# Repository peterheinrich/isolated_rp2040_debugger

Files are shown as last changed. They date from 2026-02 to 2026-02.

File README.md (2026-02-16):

# STATUS: First Prototype in Production
This design is currently untested ...

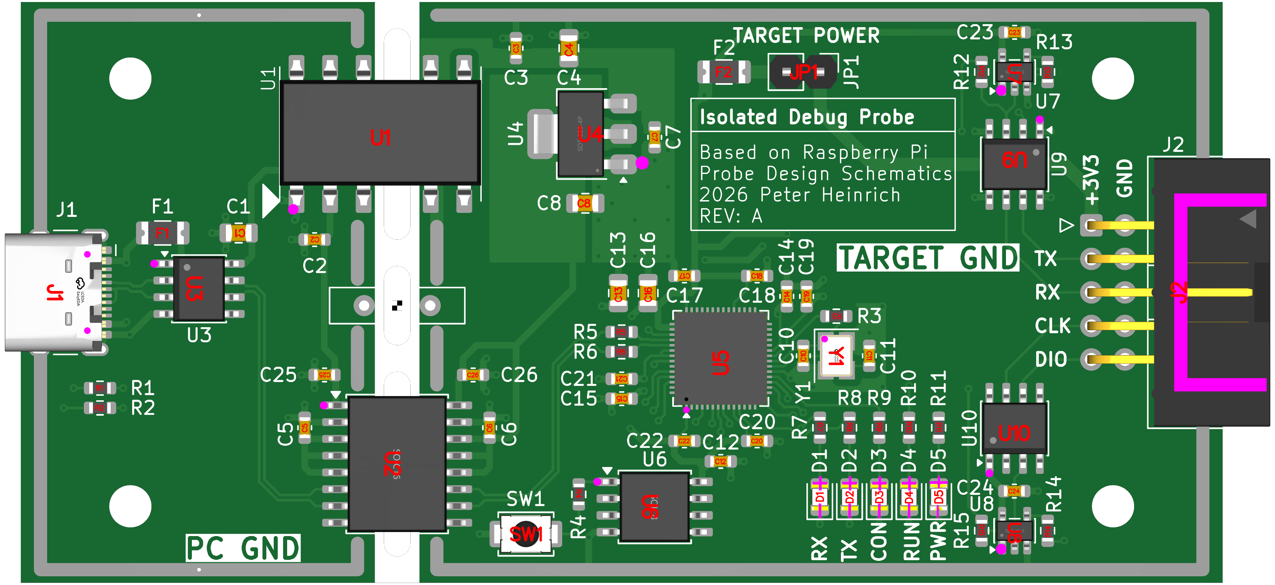
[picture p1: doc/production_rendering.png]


# Isolated RP2040 Debug Probe

An electrically isolated CMSIS-DAP debug probe based on the Raspberry Pi Debug Probe design, with full USB galvanic isolation for improved safety and robustness when debugging embedded hardware.

This project recreates the Raspberry Pi Debug Probe hardware from the published schematic and adds:

- USB full-speed isolation
- ESD protection on both USB and target ports
- Isolated DC/DC power for the target side
- Improved protection against ground loops and high-energy faults

---

## ⚠️ Important Disclaimer

This is an independent, community-made hardware design.

This project is not affiliated with, endorsed by, or supported by Raspberry Pi Ltd.
“Raspberry Pi” is a trademark of Raspberry Pi Ltd.

The original debug probe design and firmware are created by Raspberry Pi.
This repository only provides a compatible hardware implementation based on their publicly released schematic.

Original documentation:
https://www.raspberrypi.com/documentation/microcontrollers/debug-probe.html

---

## Why an Isolated Debug Probe?

Standard USB debug probes share ground between:

- your PC
- the probe
- the target device

This is usually fine — until it isn't.

Real-world embedded targets often include:
- switching power supplies
- motor drivers
- high-current loads
- long cable harnesses
- industrial equipment

Connecting a non-isolated probe can cause:

- ground loops
- USB disconnects
- corrupted SWD communication
- damage to the target
- damage to your laptop USB port

This design introduces galvanic isolation between the USB host and the target interface (SWD/UART), protecting both sides.

---

## Features

- RP2040-based CMSIS-DAP probe
- SWD debugging (OpenOCD, ... compatible)
- USB CDC UART bridge
- Full USB isolation
- Isolated target power domain
- Drop-in compatible with existing Raspberry Pi Debug Probe software

---

## Hardware Overview

The probe consists of two electrically separated domains:

### Host Side
- USB connector
- USB interface isolator

### Target Side (Isolated)
- RP2040 microcontroller
- SWD interface (SWCLK, SWDIO)
- UART (TX/RX)
- Assumes fixed 3.3V target voltage
- Can power the target (up to 50mA) if desired
- Powered through isolated DC/DC converter

Isolation is implemented using:
- USB isolator IC
- isolated DC/DC converter

No electrical ground connection exists between the PC and the target device.

---

## Firmware

The probe runs the official Raspberry Pi Debug Probe firmware for the RP2040.

Flashing instructions:
1. Connect the probe while holding the BOOTSEL button
2. The device appears as a USB mass storage drive
3. Copy the debugprobe.uf2 firmware to the drive

Firmware download:
https://github.com/raspberrypi/debugprobe/releases

---

## Building the Hardware

### Requirements
- 4-layer PCB recommended
- Hot-air or reflow assembly
- 0603 passives
- Fine-pitch soldering capability

Or simply order via JLCPCB

Files provided in this repository:
- Schematic
- PCB layout
- Gerbers
- BOM
- Pick & Place

---

## Known Limitations

- No more tha 50mA of target power may be supplied by the probe
- USB full-speed only (12 Mbps), same as the original debug probe

---

## License

### This repository
Hardware design files in this repository are released under the CERN-OHL-S v2.

### Raspberry Pi materials
Portions of the information (such as pinout descriptions) are derived from Raspberry Pi documentation, which is licensed under Creative Commons.

© Raspberry Pi Ltd.
Used with attribution.

---

## Acknowledgements

This project would not exist without the excellent work by the Raspberry Pi engineers who designed the original Debug Probe and released its schematic and firmware publicly.

If you simply need a normal probe, please consider buying the official product — it directly supports Raspberry Pi and their open hardware efforts.

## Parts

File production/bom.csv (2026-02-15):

Designator | Footprint | Quantity | Value | LCSC Part #
C1, C4, C8 | 0805 | 3 | 10u | C15850
C10, C11 | 0603 | 2 | 15p | C1644
C12, C14, C15, C17, C18, C19, C2, C20, C21, C22, C23, C24, C25, C26, C3, C7 | 0603 | 16 | 100n | C14663
C13, C16 | 0805 | 2 | 2u2 | C377773
C5, C6 | 0603 | 2 | 1u | C15849
C9 | C_Disc_D10.0mm_W2.5mm_P5.00mm | 1 | 1n | C499502
D1, D3 | 0805 | 2 | GN | C2297
D2, D4 | 0805 | 2 | YL | C2296
D5 | 0805 | 1 | RD | C84256
F1 | 1206 | 1 | 250mA | C20798
F2 | 1206 | 1 | 50mA | C20797
J1 | USB_C_Receptacle_HCTL_HC-TYPE-C-16P-01A | 1 | USB_C_Receptacle_USB2.0_14P | C2894897
J2 | IDC-Header_2x05_P2.54mm_Horizontal | 1 | DBG-TGT | C9140
JP1 | PinHeader_1x02_P2.54mm_Vertical | 1 | Jumper_2_Open | C5360898
R1, R2 | 0603 | 2 | 5k1 | C23186
R10, R11, R7, R8, R9 | 0603 | 5 | 470 | C23179
R12, R15 | 0603 | 2 | 100 | C22775
R13, R14 | 0603 | 2 | 22 | C1203
R3, R4, R5, R6 | 0603 | 4 | 1k | C21190
SW1 | SW_SPST_TS-1088-xR020 | 1 | SW_Push | C720477
U1 | SMD_DCDC | 1 | ~ | C115958
U10, U3, U9 | SOIC-8_3.9x4.9mm_P1.27mm | 3 | USB6B1 | C10508
U2 | SOIC-16W_7.5x10.3mm_P1.27mm | 1 | ADUM3160 | C284149
U4 | SOT-223-3_TabPin2 | 1 | NCP1117-3.3_SOT223 | C6186
U5 | QFN-56-1EP_7x7mm_P0.4mm_EP3.2x3.2mm | 1 | RP2040 | C2040
U6 | SOIC-8_5.3x5.3mm_P1.27mm | 1 | W25Q16JVSS | C82317
U7, U8 | SOT-23-5 | 2 | 74AUP1G17 | C183012
Y1 | Crystal_SMD_Abracon_ABM8AIG-4Pin_3.2x2.5mm | 1 | 12MHz | C9002

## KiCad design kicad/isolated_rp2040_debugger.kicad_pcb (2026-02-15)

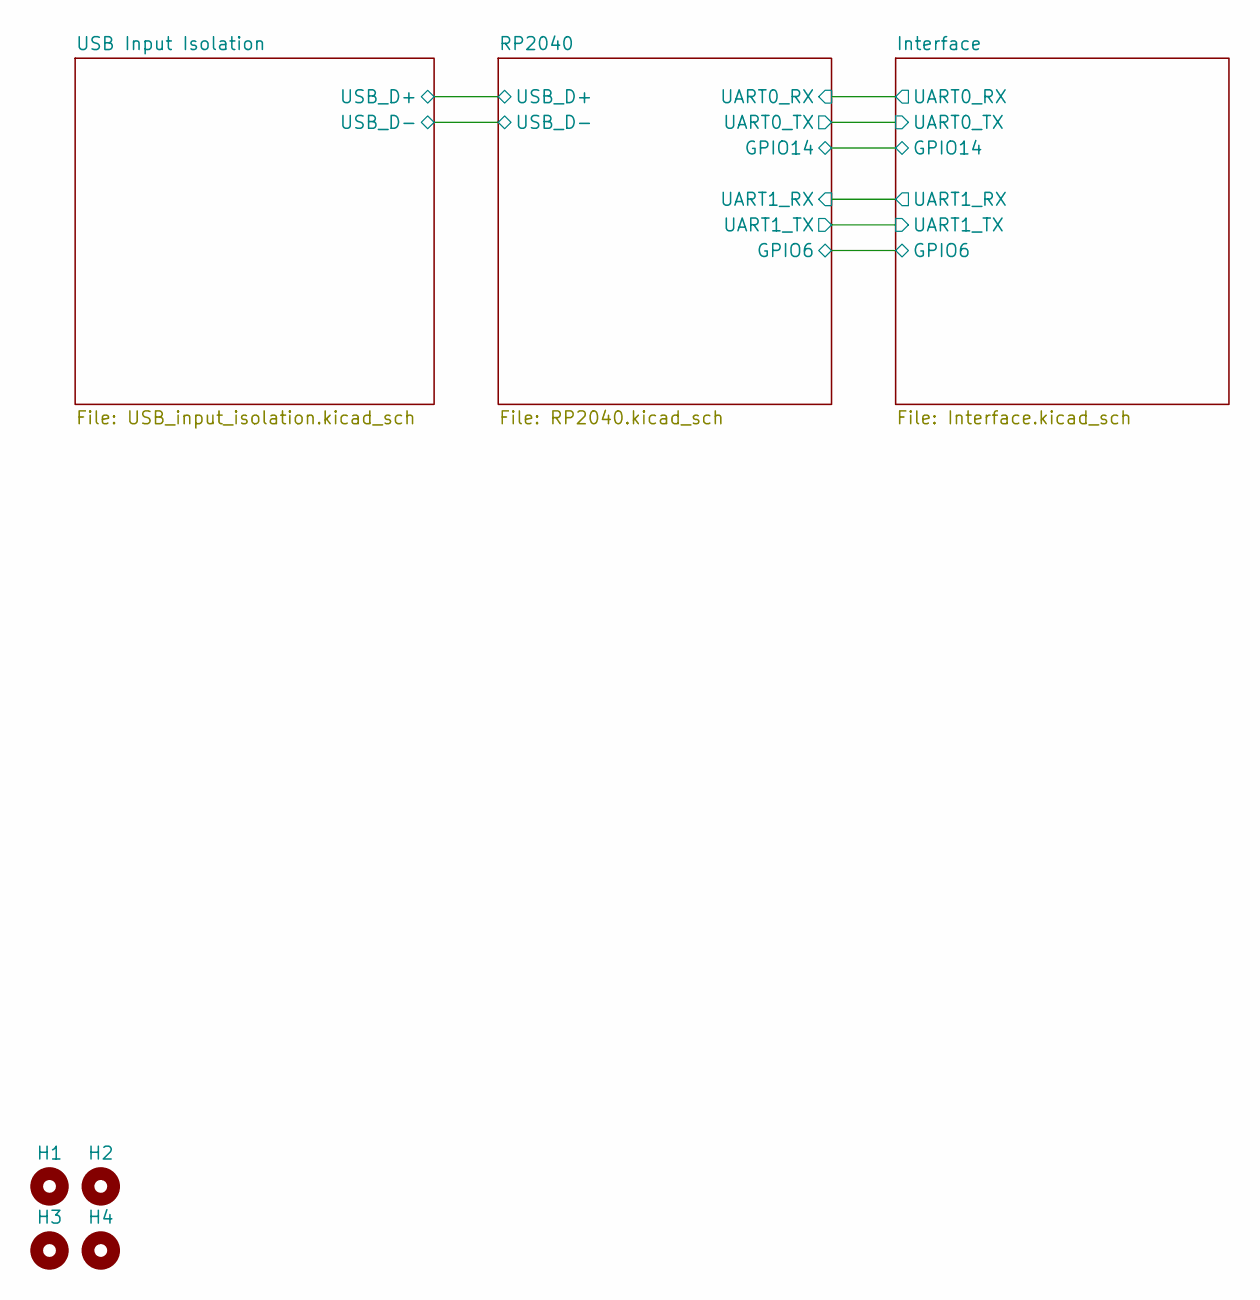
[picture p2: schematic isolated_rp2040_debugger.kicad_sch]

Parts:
H1, H2, H3, H4: MountingHole; MountingHole_3.2mm_M3

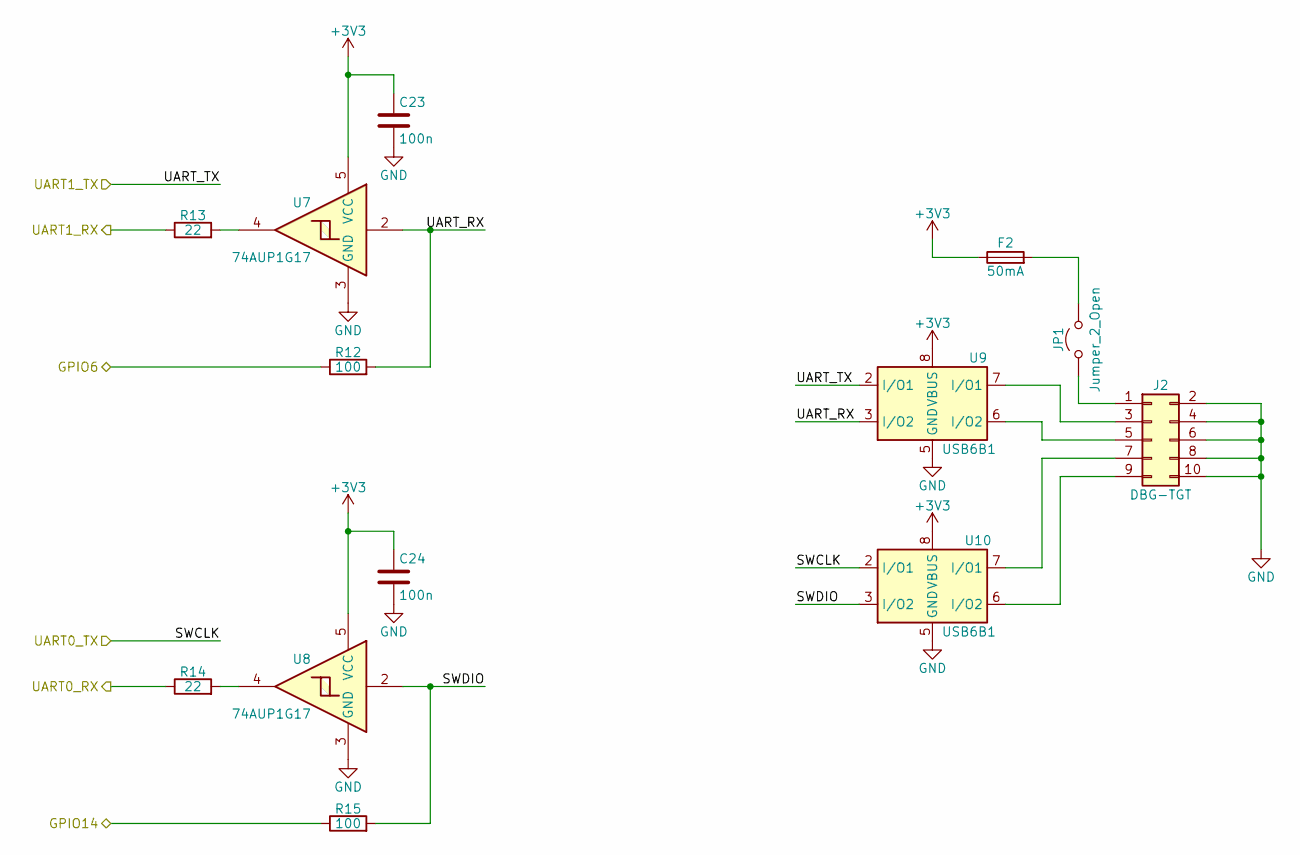
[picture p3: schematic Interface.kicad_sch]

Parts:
C23, C24: 100n; C_0603_1608Metric; MPN_LCSC CC0603KRX7R9BB104; LCSC C14663
F2: 50mA; Fuse_1206_3216Metric; MPN_LCSC SMD1206P005TF; LCSC C20797
J2: DBG-TGT; IDC-Header_2x05_P2.54mm_Horizontal; MPN_LCSC 2.54-2*5P弯简牛; LCSC C9140
JP1: Jumper_2_Open; PinHeader_1x02_P2.54mm_Vertical; MPN_LCSC PZ2.54-1*2; LCSC C5360898
R12, R15: 100; R_0603_1608Metric; MPN_LCSC 0603WAF1000T5E; LCSC C22775
R13, R14: 22; R_0603_1608Metric; MPN_LCSC 0603WAJ0220T5E; LCSC C1203
U7, U8: 74AUP1G17; SOT-23-5; MPN_LCSC SN74AUP1G17DBVR; LCSC C183012
U9, U10: USB6B1; SOIC-8_3.9x4.9mm_P1.27mm; MPN_LCSC USB6B1RL; LCSC C10508

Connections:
+3V3: C23.1, C24.1, F2.1, U7.5 (VCC), U8.5 (VCC), U9.1 (VBUS), U9.8 (VBUS), U10.1 (VBUS), U10.8 (VBUS); also elsewhere on the board
/Interface/GPIO6: R12.1; also elsewhere on the board
/Interface/GPIO14: R15.1; also elsewhere on the board
/Interface/SWCLK: U10.2 (I/O1); also elsewhere on the board
/Interface/SWDIO: R15.2, U8.2, U10.3 (I/O2)
/Interface/UART0_RX: R14.1; also elsewhere on the board
/Interface/UART1_RX: R13.1; also elsewhere on the board
/Interface/UART_RX: R12.2, U7.2, U9.3 (I/O2)
/Interface/UART_TX: U9.2 (I/O1); also elsewhere on the board
GND: C23.2, C24.2, J2.2, J2.4, J2.6, J2.8, J2.10, U7.3 (GND), U8.3 (GND), U9.4 (GND), U9.5 (GND), U10.4 (GND), U10.5 (GND); also elsewhere on the board
unnamed: J2.1, JP1.1 (A)
unnamed: J2.3, U9.7 (I/O1)
unnamed: J2.5, U9.6 (I/O2)
unnamed: J2.7, U10.7 (I/O1)
unnamed: J2.9, U10.6 (I/O2)
unnamed: F2.2, JP1.2 (B)
unnamed: R13.2, U7.4
unnamed: R14.2, U8.4

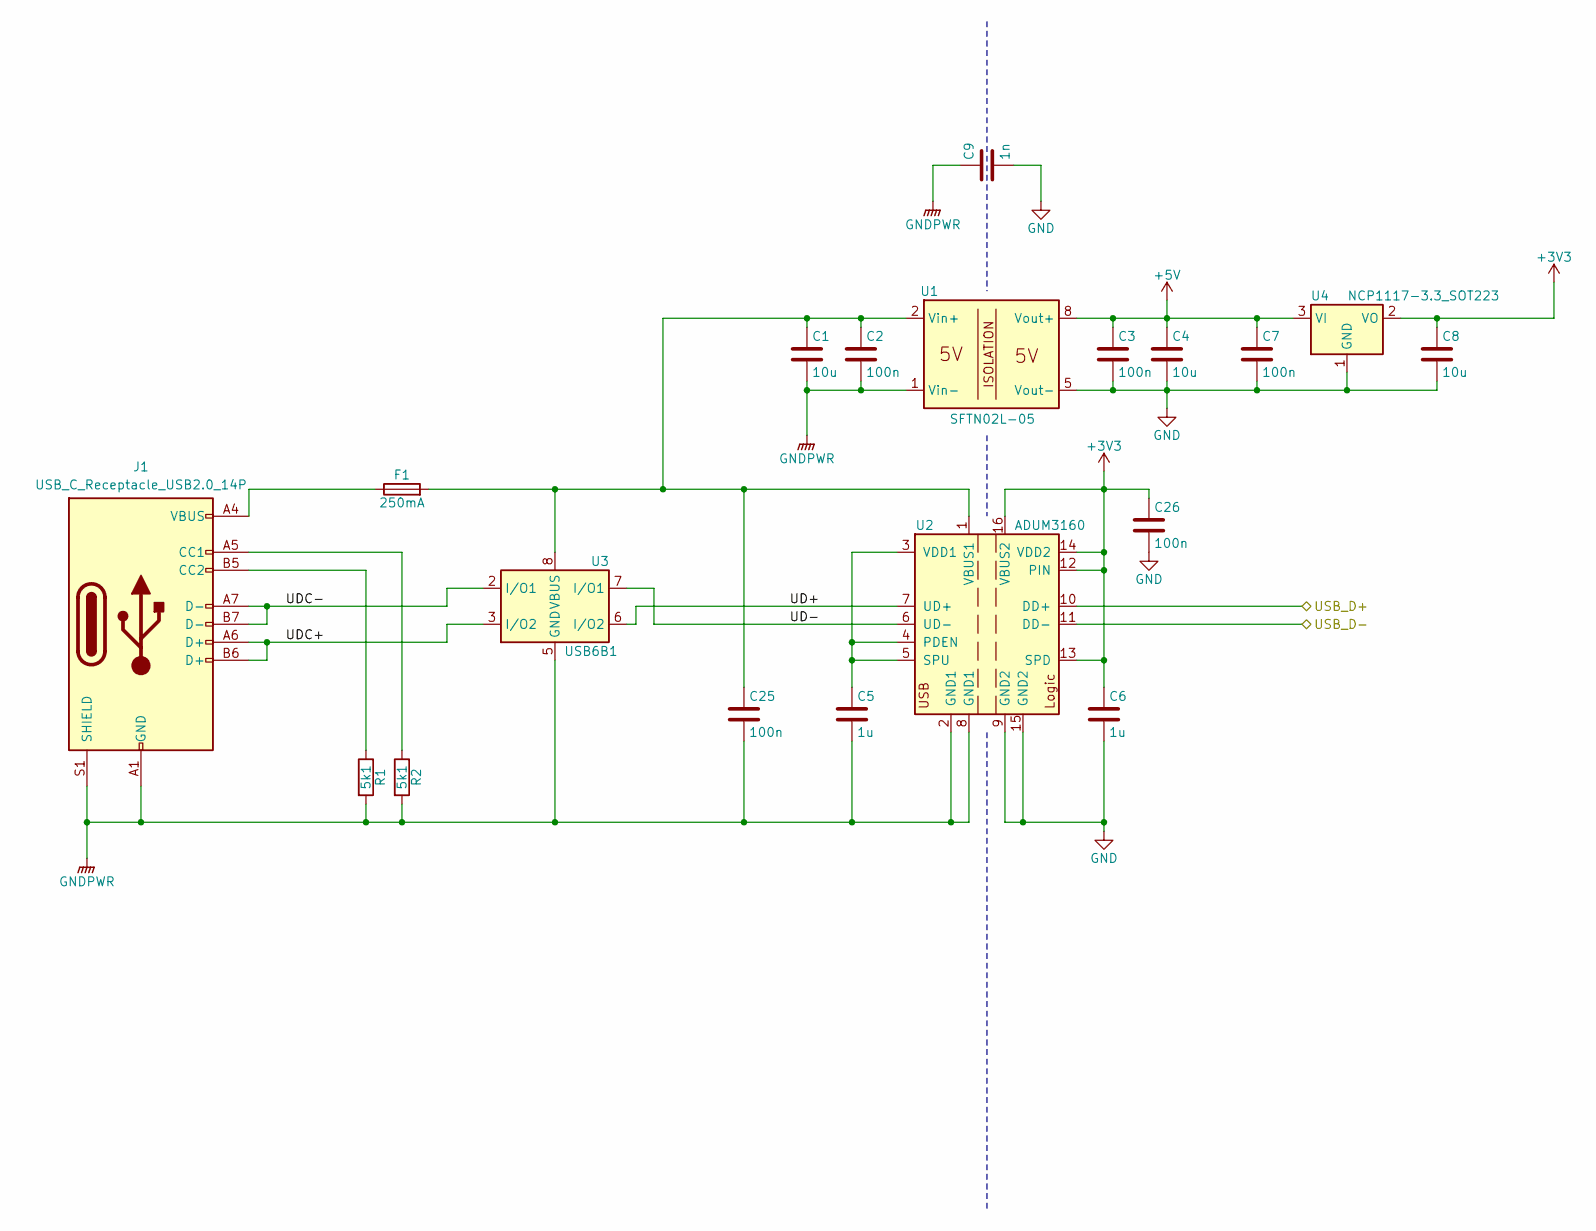
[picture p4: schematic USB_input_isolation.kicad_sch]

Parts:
C1, C4, C8: 10u; C_0805_2012Metric; MPN_LCSC CL21A106KAYNNNE; LCSC C15850
C2, C3, C7, C25, C26: 100n; C_0603_1608Metric; MPN_LCSC CC0603KRX7R9BB104; LCSC C14663
C5, C6: 1u; C_0603_1608Metric; MPN_LCSC CL10A105KB8NNNC; LCSC C15849
C9: 1n; C_Disc_D10.0mm_W2.5mm_P5.00mm; MPN_LCSC VY1102M35Y5UQ63V0; LCSC C499502
F1: 250mA; Fuse_1206_3216Metric; MPN_LCSC SMD1206P025TF; LCSC C20798
J1: USB_C_Receptacle_USB2.0_14P; USB_C_Receptacle_HCTL_HC-TYPE-C-16P-01A; MPN_LCSC HC-TYPE-C-16P-01A; LCSC C2894897
R1, R2: 5k1; R_0603_1608Metric; MPN_LCSC 0603WAF5101T5E; LCSC C23186
U1: SMD_DCDC; MPN_LCSC 13DS1-05S05NNL; LCSC C115958
U2: ADUM3160; SOIC-16W_7.5x10.3mm_P1.27mm; MPN_LCSC ADUM3160BRWZ-RL; LCSC C284149
U3: USB6B1; SOIC-8_3.9x4.9mm_P1.27mm; MPN_LCSC USB6B1RL; LCSC C10508
U4: NCP1117-3.3_SOT223; SOT-223-3_TabPin2; MPN_LCSC AMS1117-3.3; LCSC C6186

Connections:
+3V3: C6.1, C8.1, C26.1, U2.12 (PIN), U2.13 (SPD), U2.14 (VDD2), U2.16 (VBUS2), U4.2 (VO); also elsewhere on the board
+5V: C3.1, C4.1, C7.1, U1.8 (Vout+), U4.3 (VI)
/RP2040/USB_D+: U2.10 (DD+); also elsewhere on the board
/RP2040/USB_D-: U2.11 (DD-); also elsewhere on the board
/USB Input Isolation/UD+: U2.7 (UD+), U3.6 (I/O2)
/USB Input Isolation/UD-: U2.6 (UD-), U3.7 (I/O1)
/USB Input Isolation/UDC+: J1.A6 (D+), J1.B6 (D+), U3.3 (I/O2)
/USB Input Isolation/UDC-: J1.A7 (D-), J1.B7 (D-), U3.2 (I/O1)
GND: C3.2, C4.2, C6.2, C7.2, C8.2, C9.2, C26.2, U1.5 (Vout-), U2.9 (GND2), U2.15 (GND2), U4.1 (GND); also elsewhere on the board
GNDPWR: C1.2, C2.2, C5.2, C9.1, C25.2, J1.A1 (GND), J1.A12 (GND), J1.B1 (GND), J1.B12 (GND), J1.S1 (SHIELD), R1.2, R2.2, U1.1 (Vin-), U2.2 (GND1), U2.8 (GND1), U3.4 (GND), U3.5 (GND)
unnamed: F1.1, J1.A4 (VBUS), J1.A9 (VBUS), J1.B4 (VBUS), J1.B9 (VBUS)
unnamed: J1.A5 (CC1), R2.1
unnamed: J1.B5 (CC2), R1.1
unnamed: C1.1, C2.1, C25.1, F1.2, U1.2 (Vin+), U2.1 (VBUS1), U3.1 (VBUS), U3.8 (VBUS)
unnamed: C5.1, U2.3 (VDD1), U2.4 (PDEN), U2.5 (SPU)

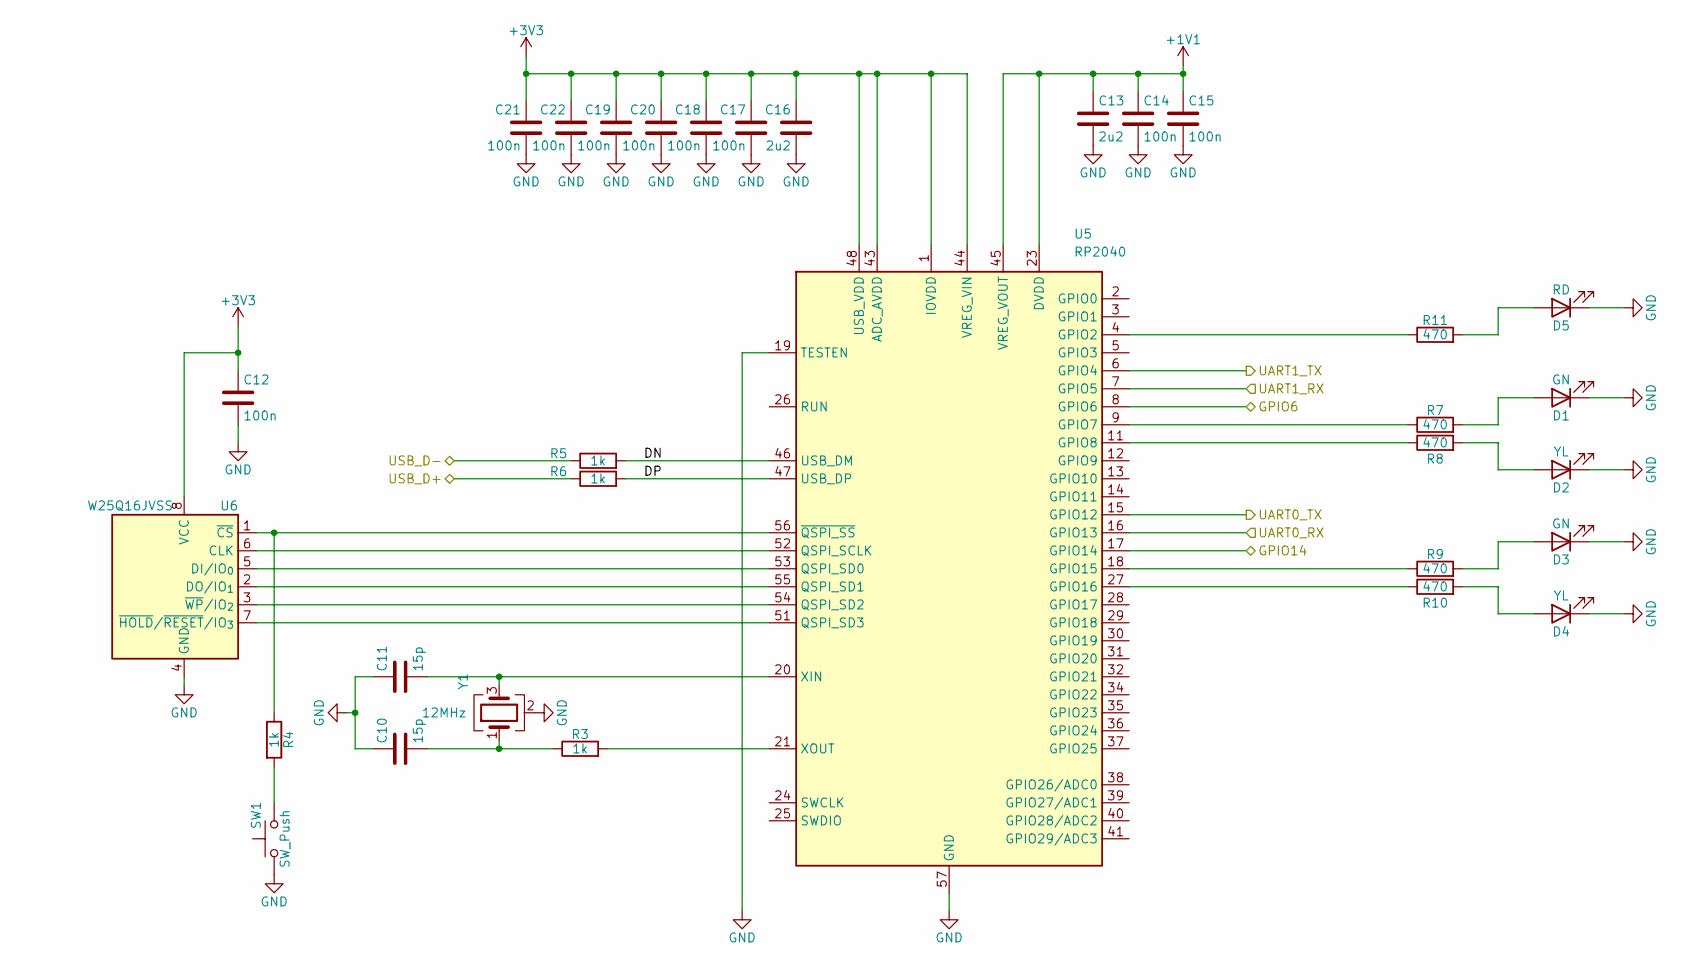
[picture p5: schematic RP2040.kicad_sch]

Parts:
C10, C11: 15p; C_0603_1608Metric; MPN_LCSC CL10C150JB8NNNC; LCSC C1644
C12, C14, C15, C17, C18, C19, C20, C21, C22: 100n; C_0603_1608Metric; MPN_LCSC CC0603KRX7R9BB104; LCSC C14663
C13, C16: 2u2; C_0805_2012Metric; MPN_LCSC CL21A225KBQNNNE; LCSC C377773
D1, D3: GN; LED_0805_2012Metric; MPN_LCSC KT-0805G; LCSC C2297
D2, D4: YL; LED_0805_2012Metric; MPN_LCSC KT-0805Y; LCSC C2296
D5: RD; LED_0805_2012Metric; MPN_LCSC NCD0805R1; LCSC C84256
R3, R4, R5, R6: 1k; R_0603_1608Metric; MPN_LCSC 0603WAF1001T5E; LCSC C21190
R7, R8, R9, R10, R11: 470; R_0603_1608Metric; MPN_LCSC 0603WAF4700T5E; LCSC C23179
SW1: SW_Push; SW_SPST_TS-1088-xR020; MPN_LCSC TS-1088-AR02016; LCSC C720477
U5: RP2040; QFN-56-1EP_7x7mm_P0.4mm_EP3.2x3.2mm; MPN_LCSC RP2040; LCSC C2040
U6: W25Q16JVSS; SOIC-8_5.3x5.3mm_P1.27mm; MPN_LCSC W25Q16JVSSIQ; LCSC C82317
Y1: 12MHz; Crystal_SMD_Abracon_ABM8AIG-4Pin_3.2x2.5mm; MPN_LCSC X322512MSB4SI; LCSC C9002

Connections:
+1V1: C13.1, C14.1, C15.1, U5.23 (DVDD), U5.45 (VREG_VOUT), U5.50 (DVDD)
+3V3: C12.1, C16.1, C17.1, C18.1, C19.1, C20.1, C21.1, C22.1, U5.1 (IOVDD), U5.10 (IOVDD), U5.22 (IOVDD), U5.33 (IOVDD), U5.42 (IOVDD), U5.43 (ADC_AVDD), U5.44 (VREG_VIN), U5.48 (USB_VDD), U5.49 (IOVDD), U6.8 (VCC); also elsewhere on the board
/Interface/GPIO6: U5.8 (GPIO6); also elsewhere on the board
/Interface/GPIO14: U5.17 (GPIO14); also elsewhere on the board
/Interface/SWCLK: U5.15 (GPIO12); also elsewhere on the board
/Interface/UART0_RX: U5.16 (GPIO13); also elsewhere on the board
/Interface/UART1_RX: U5.7 (GPIO5); also elsewhere on the board
/Interface/UART_TX: U5.6 (GPIO4); also elsewhere on the board
/RP2040/DN: R5.2, U5.46 (USB_DM)
/RP2040/DP: R6.2, U5.47 (USB_DP)
/RP2040/USB_D+: R6.1; also elsewhere on the board
/RP2040/USB_D-: R5.1; also elsewhere on the board
GND: C10.1, C11.1, C12.2, C13.2, C14.2, C15.2, C16.2, C17.2, C18.2, C19.2, C20.2, C21.2, C22.2, D1.1 (K), D2.1 (K), D3.1 (K), D4.1 (K), D5.1 (K), SW1.1, U5.19 (TESTEN), U5.57 (GND), U6.4 (GND), Y1.2 (G), Y1.4 (G); also elsewhere on the board
unnamed: C10.2, R3.1, Y1.1
unnamed: D1.2 (A), R7.2
unnamed: D2.2 (A), R8.2
unnamed: D3.2 (A), R9.2
unnamed: D4.2 (A), R10.2
unnamed: D5.2 (A), R11.2
unnamed: R4.2, SW1.2
unnamed: R11.1, U5.4 (GPIO2)
unnamed: R7.1, U5.9 (GPIO7)
unnamed: R8.1, U5.11 (GPIO8)
unnamed: R9.1, U5.18 (GPIO15)
unnamed: R10.1, U5.27 (GPIO16)
unnamed: U5.52 (QSPI_SCLK), U6.6 (CLK)
unnamed: U5.53 (QSPI_SD0), U6.5 (DI/IO_{0})
unnamed: U5.55 (QSPI_SD1), U6.2 (DO/IO_{1})
unnamed: U5.54 (QSPI_SD2), U6.3 (~WP/IO_{2})
unnamed: U5.51 (QSPI_SD3), U6.7 (~HOLD/~RESET/IO_{3})
unnamed: C11.2, U5.20 (XIN), Y1.3
unnamed: R3.2, U5.21 (XOUT)
unnamed: R4.1, U5.56 (~QSPI_SS), U6.1 (~CS)

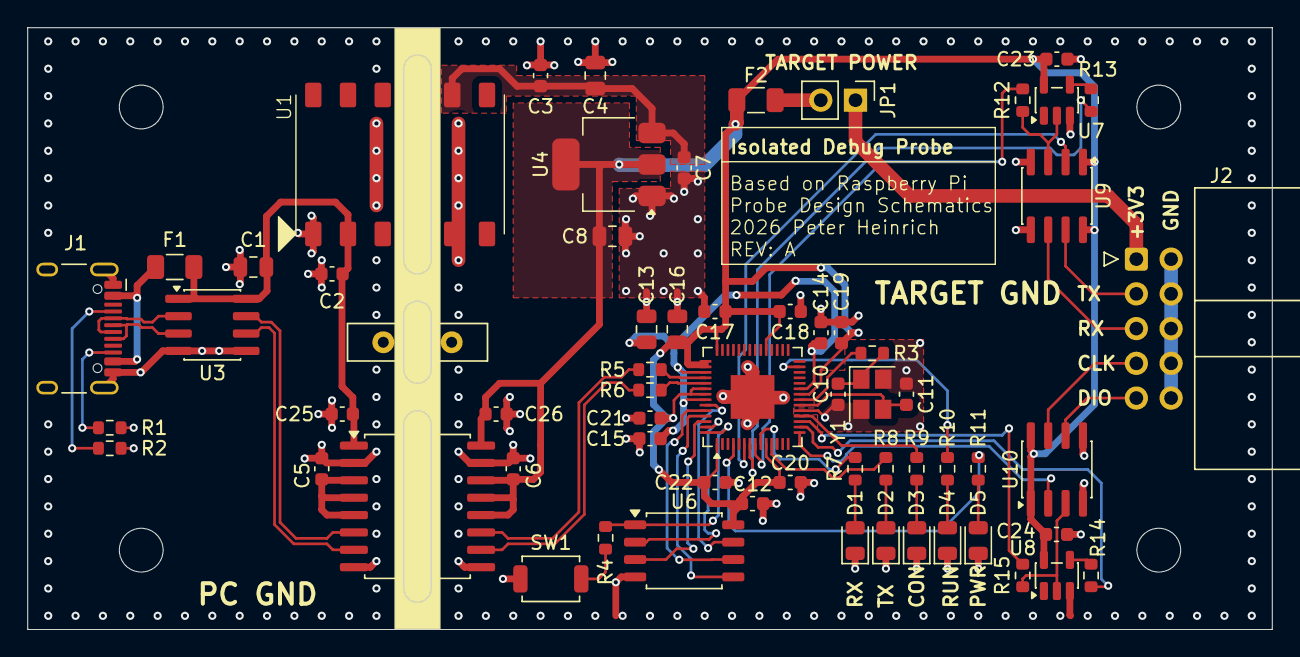
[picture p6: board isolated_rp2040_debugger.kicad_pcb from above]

Board: 4 copper layers, 91.0 x 44.0 mm, 67 parts (0 on the bottom side), 54 nets.

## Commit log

2026-02-15 Rev_A JLCPCB Production
    [Interface.kicad_sch, RP2040.kicad_sch, USB_input_isolation.kicad_sch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]
2026-02-15 Add status section to README
    Added status update for the prototype.
2026-02-16 Adding production rendering of PCB
2026-02-16 Remove negative voltage protection from README
